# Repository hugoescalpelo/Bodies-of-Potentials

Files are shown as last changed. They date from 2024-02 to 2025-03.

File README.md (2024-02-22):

# Bodies of Potentials
This repository contains details of the maintenance of Bodies of Potentials, an artwork of [Luis Enrique Zela-Koort](https://luisenriquezk.com/), part of [All the Posible Pulses](https://luisenriquezk.com/all_the_possible_pulses/) series.

You can see it working on instagram https://www.instagram.com/p/C0fhJ_dCAHn/

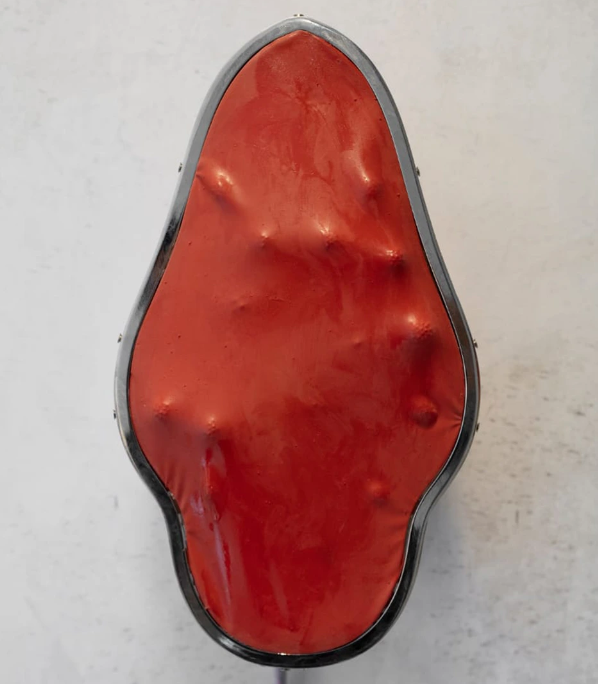
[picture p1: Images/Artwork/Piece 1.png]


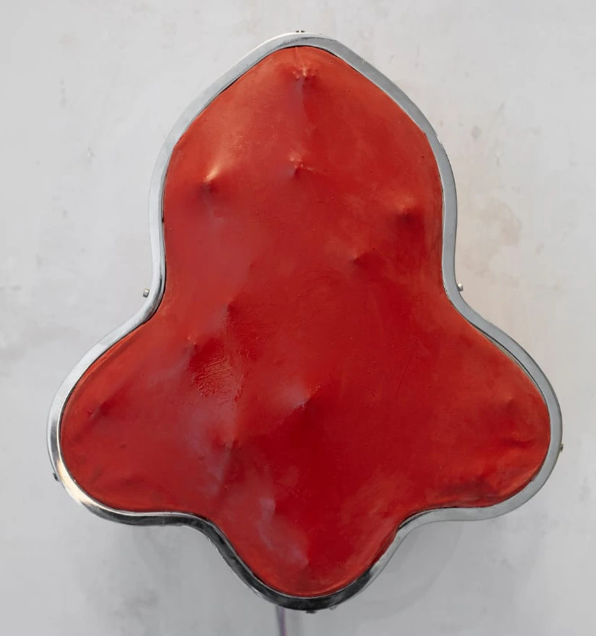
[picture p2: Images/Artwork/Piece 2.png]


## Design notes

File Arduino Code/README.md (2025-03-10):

## Arduino Code

This Arduino code has a history. Check "Hugo Code" Folder, legacy is original code, just for reference.

- I received de original Code
- I map the circuit based on this code
- I test this code alive
- I found the mechanical problems of this code
- Too much friction
- Re print some of the 3d Printed pieces and find new friction points
- Reprinted unsuccesfully
- Reprinted unsuccesfully
- Reprinted unsuccesfully
- Reprinted unsuccesfully
- Reprinted unsuccesfully
- Spring needed
- Reprinted unsuccesfully
- Reprinted unsuccesfully
- Reprinted unsuccesfully
- Reprinted unsuccesfully
- Reprinted succesfully
- Installation problems
- Reprinted unsuccesfully
- Reprinted unsuccesfully
- Reprinted unsuccesfully
- Reprinted unsuccesfully
- Lubricaion needed, silicon WD40 won't make it
- Reprinted unsuccesfully
- Reprinted unsuccesfully
- Reprinted unsuccesfully
- 360 degree motor founded
- All of the motors are 360 degree :()
- Reprinted unsuccesfully
- Reprinted unsuccesfully
- Reprinted unsuccesfully
- Reprinted unsuccesfully
- Reprinted unsuccesfully
- Reprinted unsuccesfully
- Reprinted succesfully. Original Pieces need a 2mm bore up.
- Reprinted unsuccesfully
- Reprinted unsuccesfully
- Reprinted unsuccesfully
- Reprinted unsuccesfully
- Reprinted unsuccesfully
- Why Im like this? I will doom humanity
- Reprinted unsuccesfully
- Reprinted unsuccesfully
- Reprinted unsuccesfully
- Reprinted unsuccesfully
- Reprinted unsuccesfully
- Reprinted unsuccesfully
- Reprinted unsuccesfully
- Reprinted unsuccesfully
- Reprinted unsuccesfully
- Reprinted unsuccesfully
- Just watched the repo
- Just watched the repo
- Just watched the repo
- Just watched the repo
- Just watched the repo
- Just watched the repo
- Just watched the repo
- Oh my god, why this printer does not work
- I Fixed it. Now all prints are beautifull
- Ok, now I can test rigidity and center of servos
- Damn, I need to rewire everything
- Wow, colors! 
- Will this epoxy ever cuajar?
- Earthquake!
- I' so sorry Luis
- Luis, if you ever read this and work with me again, let me let you know I´m not usually like this
- Well, the first test in situ is available

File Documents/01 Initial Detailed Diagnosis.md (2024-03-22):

# Initial Detailed Diagnosis

An extensive revision was made, confirming the main poinst of diagnosis and adding some new recommendations.

A video resume is available here https://youtu.be/R9Tb3EtviOM

## Piece A

### Reported problems

- Damage to the latex membrane after a long period of worktime.
- Water based constant lubrication is needed.
- Some motors stop working due to friction.

### Original diagnosis

- Re design of servo motor holder is needed.
- Re print of spheres with PET-G is needed.
- Substitution of Servo Motors is needed. Metalic gear will be used.
- Aluminum sheet coating to the depth wheel is recommended.
- Silicon based lubricant will be applied.

### New Discoveries

An important difference in damage to the latex membrane was noticed between Piece A and Piece B. Piece A shows damage very noticeable, piece B shows almost no damage. It might be caused due to tension or difference in tickness, but the main cause could be related to the rotary wheel using the membrane tension to reposition the spheres. A spring will be added to every wheel axis to retract without depending of the membrane tension.

The source has no specifications. Sticker with info was removed. Due to its size, power coud be insufficient, causing the motors to stop working. Measurements are in order. If insufficient, source will be replaced.

## Piece B

### Repoted problems
- Damage to the latex membrane after a long period of worktime.
- Water based constant lubrication is needed.
- Some motors stop working due to friction.

### Original diagnosis

- Re design of servo motor holder is needed.
- Re print of spheres with PET-G is needed.
- Substitution of Servo Motors is needed. Metalic gear will be used.
- Aluminum sheet coating to the depth wheel is recommended.
- Silicon based lubricant will be applied.

### New Discoveries

Circuit maintenance is needed. Some conectors are unplugged.

Driver for DC motors might be insufficient, substitusion is needed.

The source has no specifications. Sticker with info was removed. Due to its size, power might be insufficient. Testing and measurements are needed to determine if current is enough. If insufficient, source will be replaced.

Rotary DC mThe source has no specifications. Sticker with info was removed. Due to its size, power coud be insufficient, causing the motors to stop working. Measurements are in order. If insufficient, source will be replaced.

DC motor holder for rotary functions have a very noticeable missalignment, re design of holding mechanism will be performed.

## General Extras

- An extensive test is scheduled after maintenance.
- A prescence sensor will be integrated.

## Requirements

- Step files were proided.
- Electronic schematics are needed.
- Source code is needed.

## Next Steps

- This inform will be delivered to get Artist's conscent to operate the Piece A with membrane damage.
- Water based lubricant will be applied.
- Both pieces will be activated in order to determine further problems.

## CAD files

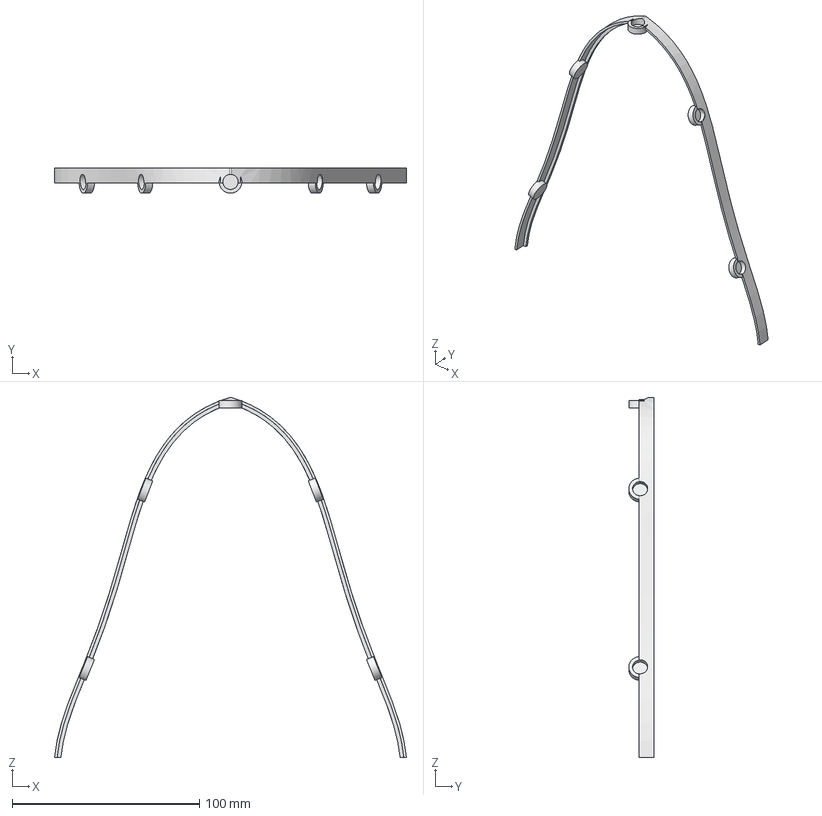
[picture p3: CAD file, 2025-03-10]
STEP/Calamar full V2 Arco A v3.step
188.0 x 13.6 x 192.3 mm

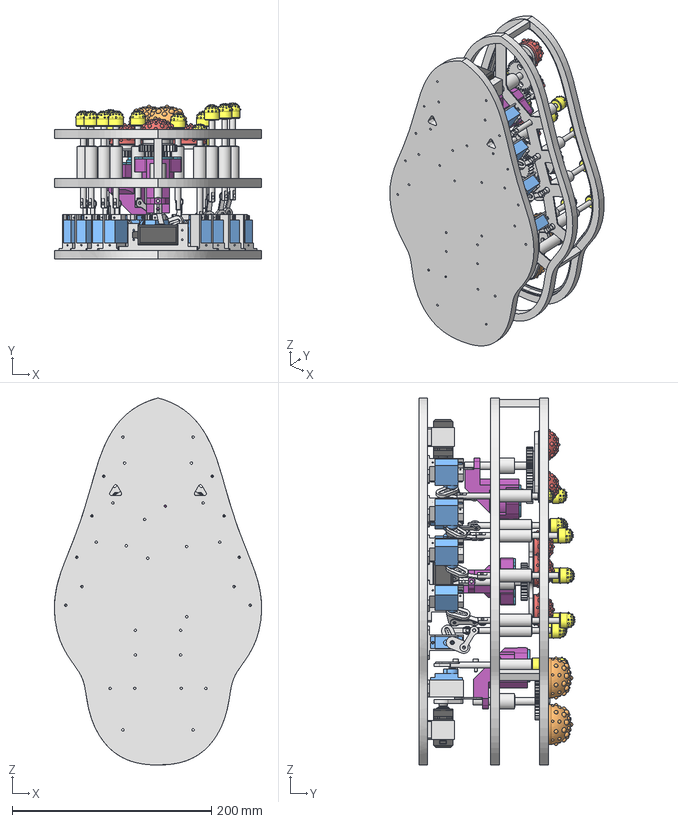
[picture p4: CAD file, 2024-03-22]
STEP/Original Files/Calamar full V2 feb28.stp
208.0 x 157.0 x 368.3 mm
Plataforma inferior v2
Acople brazo servo x 14
brazo servo 1 x 14
Micro Servo SG90 x 14
Soporte Servo sg90 x 14
brazo 20mm x 17
Perfil superior
brazo servo 4 x 3
Acople brazo servo s3003 x 3
Servo S3003 x 3
Soporte Servo s3003 x 3
Perfil ejes v2
Motor DC 10rpm x 3
Eje aluminio 9mm x 3
Eje aluminio b15 x 14
Gear1A x 3
Gear1B x 3
Bocina 6mm x 14
Bocina 9mm
Soporte b40 doble
Soporte b30 doble
Soporte b30 penta
Bola 15mm x 14
Bola 30mm x 7
Bola 40mm x 2
Soporte motor DC v3 x 3
UNI 5931 - M 3 x 10 x 6

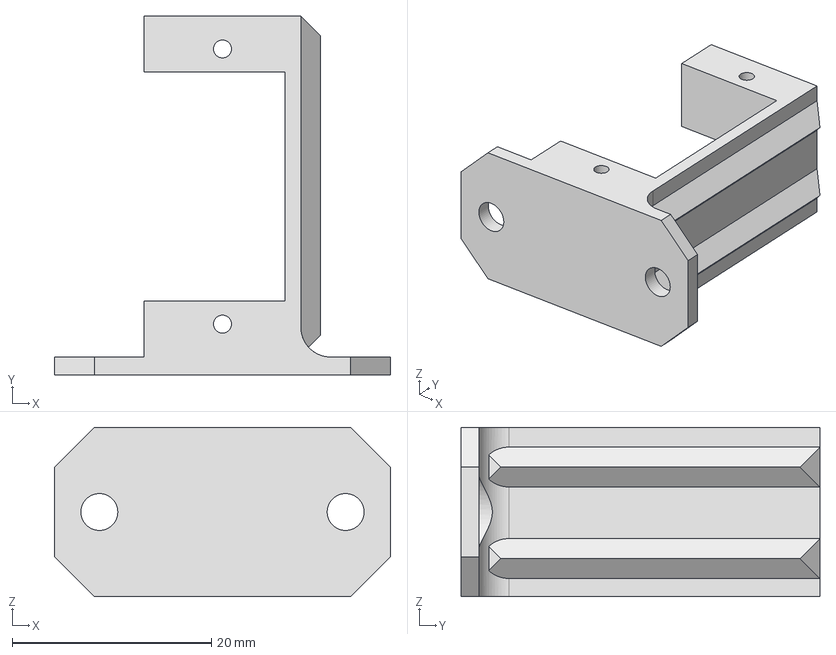
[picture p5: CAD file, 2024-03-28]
STEP/Updated Parts/Calamar full V2 feb28_Soporte Servo sg90 v2.step
33.7 x 36.0 x 17.0 mm

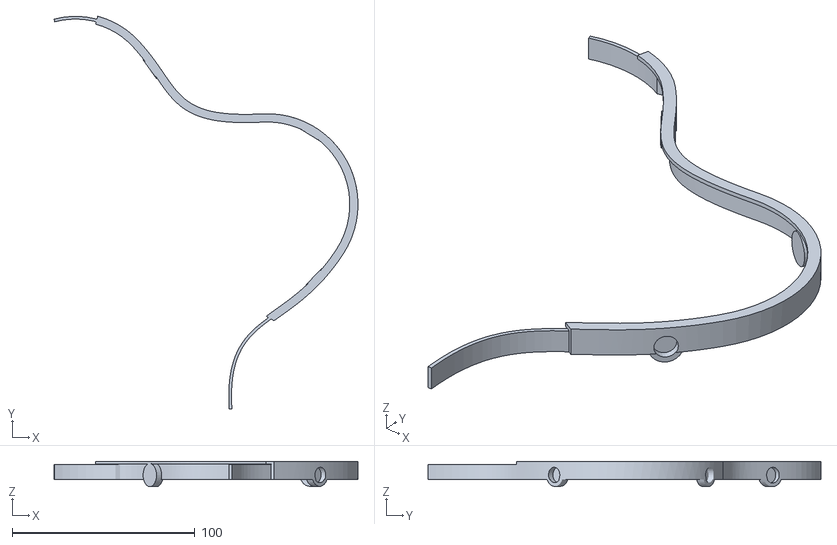
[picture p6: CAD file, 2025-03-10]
STL/Huella full v2 Arco C v5.stl
166.3 x 214.9 x 13.9

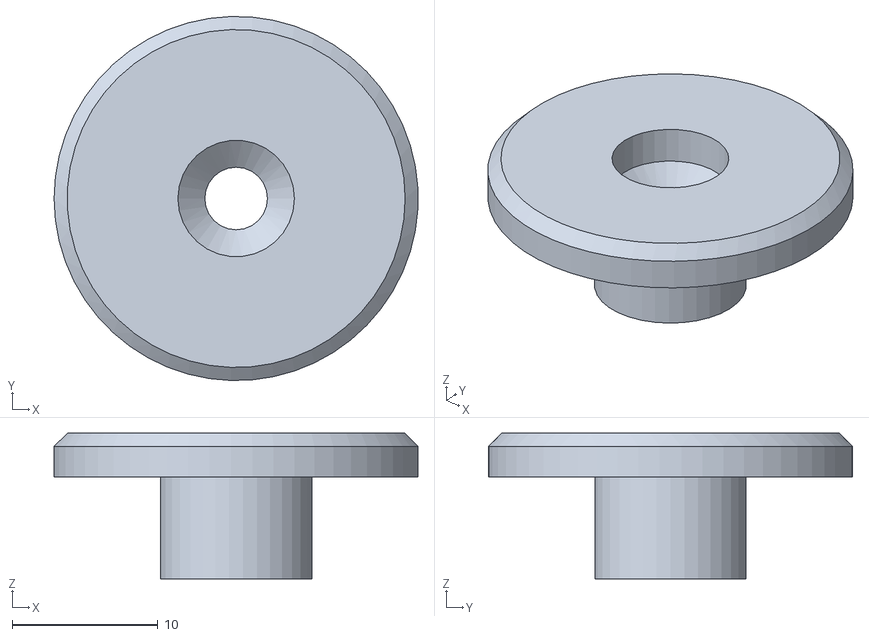
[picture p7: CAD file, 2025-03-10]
STL/Huella full v2 feb28_Gear a1 v1.stl
25.0 x 25.0 x 10.0

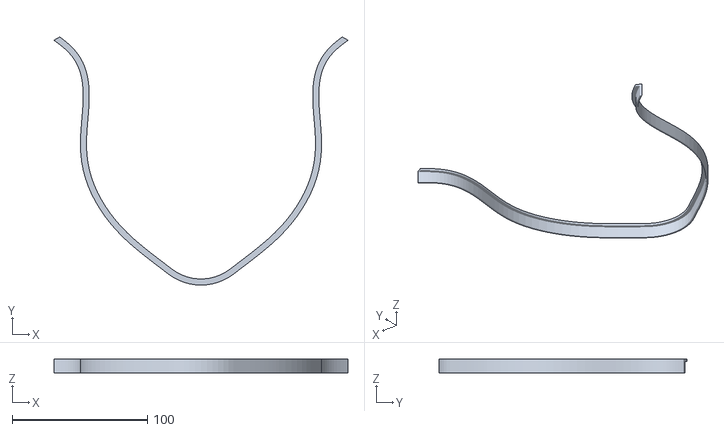
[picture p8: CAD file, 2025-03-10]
STL/Huella full v2 ArcoA v1.stl
217.3 x 183.4 x 10.0

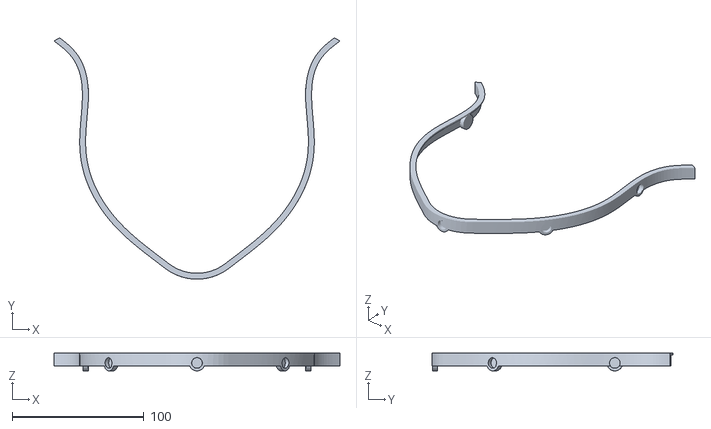
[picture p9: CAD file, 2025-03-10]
STL/Huella full v2 ArcoA v3.stl
217.3 x 183.4 x 13.5

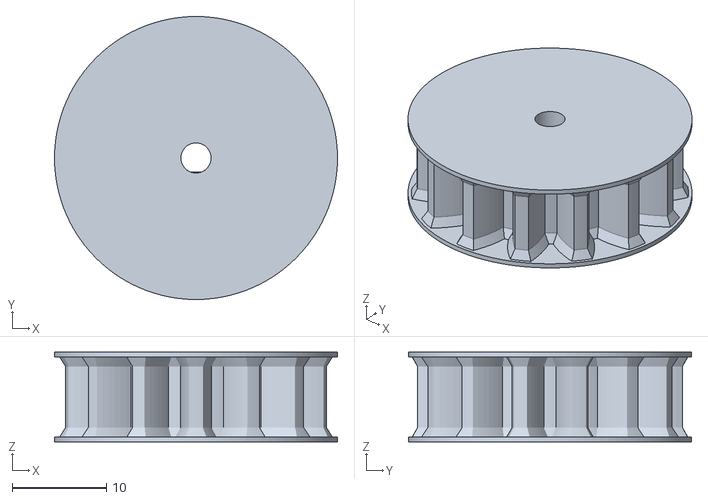
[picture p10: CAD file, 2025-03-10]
STL/Huella full v2 feb28_Gear c2 v2.stl
30.0 x 30.0 x 9.50

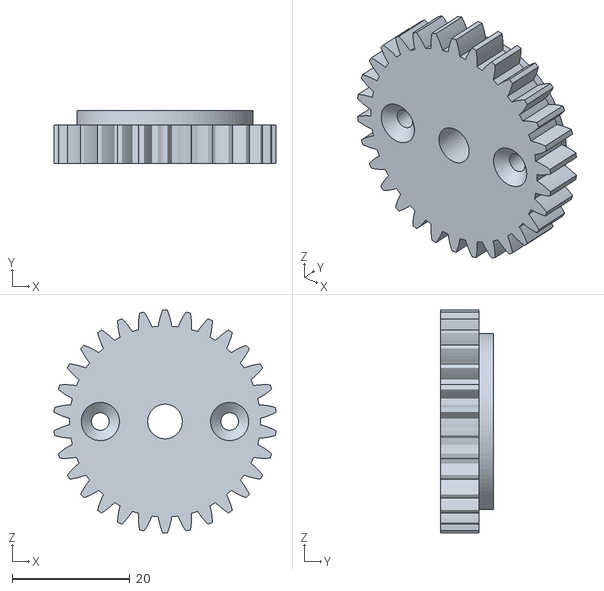
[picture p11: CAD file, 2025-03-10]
STL/Calamar full V2 feb28_Gear1A v3.stl
37.8 x 9.00 x 37.9

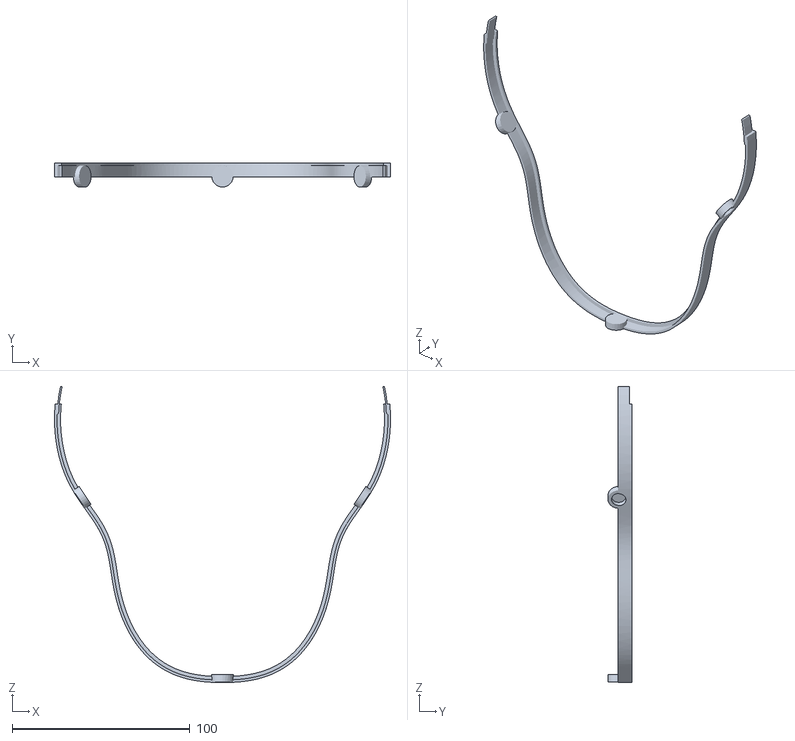
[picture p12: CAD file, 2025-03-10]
STL/Calamar full V2 Arco B v2.stl
188.8 x 13.6 x 166.4

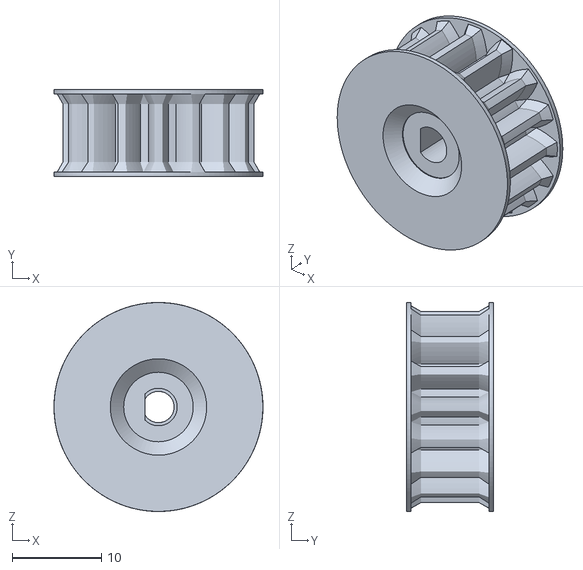
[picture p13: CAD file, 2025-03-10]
STL/Calamar full V2 feb28_Gear1B v2.stl
23.4 x 9.71 x 23.4

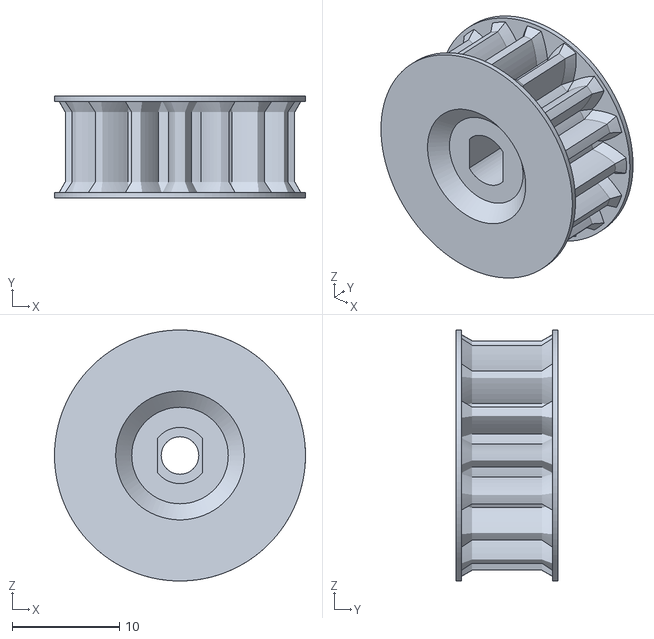
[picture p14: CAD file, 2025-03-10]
STL/Calamar full V2 feb28_Gear1B v2 big.stl
23.4 x 9.50 x 23.4

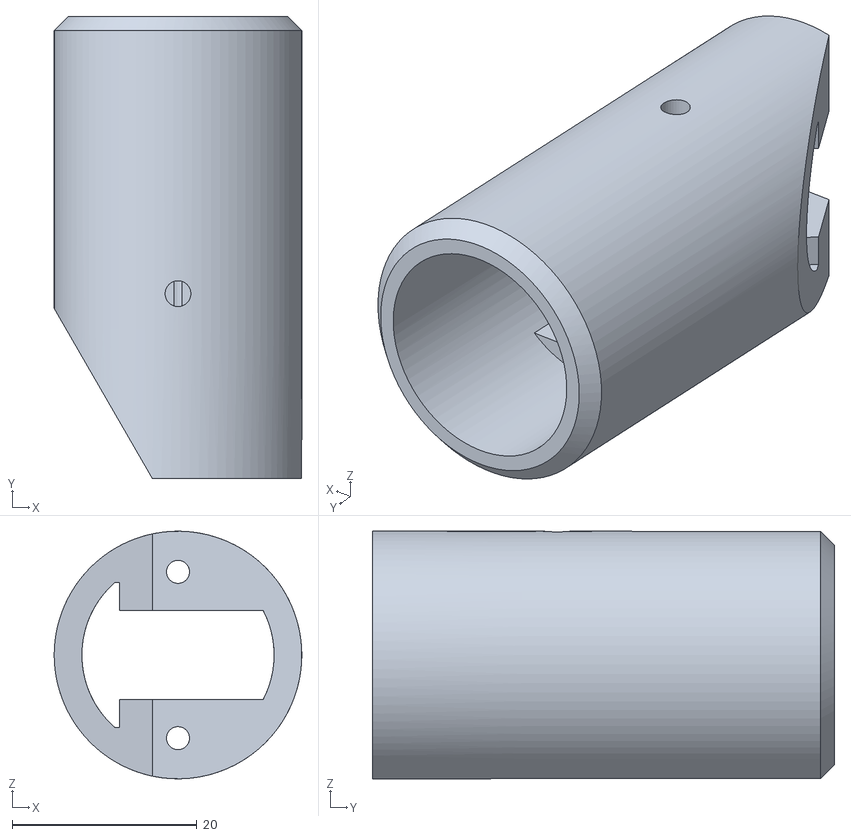
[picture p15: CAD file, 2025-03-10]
STL/Motor Nuevo Huella v3.stl
26.8 x 50.0 x 26.8

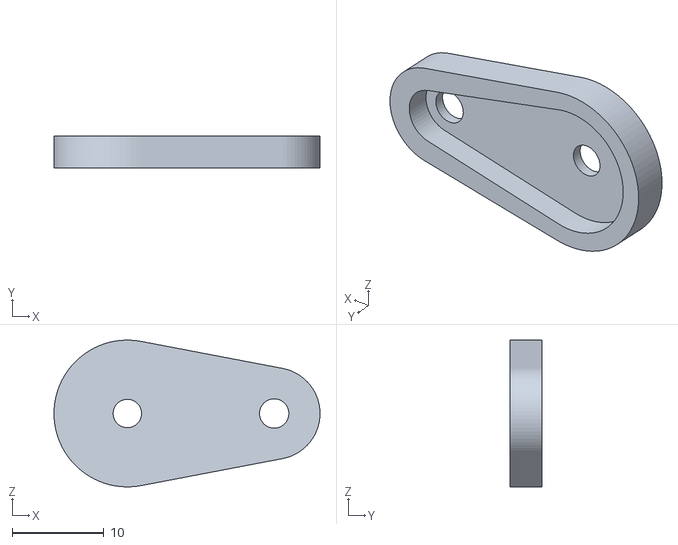
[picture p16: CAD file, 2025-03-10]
STL/Brazo Grande v2.stl
29.0 x 3.50 x 16.0

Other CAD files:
STL/Huella full v2 Arco B v2.stl
STL/Calamar full V2 Arco A v4.stl
STL/Calamar full V2 feb28_Gear1A v2.stl
STL/Calamar full V2 feb28_Soporte Servo sg90 v2.stl
STL/Base Integral v26.stl
STL/Brazo nuevo Calamar.stl
STL/Calamar - Motor Tester v1.stl
STL/Calamar - Motor Tester v2.stl
STL/Calamar - Motor Tester v3.stl
STL/Calamar_New_DC_Motor v4.stl
STL/Calamar_New_DC_Motor v5.stl
STL/Calamar_New_DC_Motor v6.stl
STL/Calamar_New_DC_Motor v7.stl
STL/plate adapter v2.stl

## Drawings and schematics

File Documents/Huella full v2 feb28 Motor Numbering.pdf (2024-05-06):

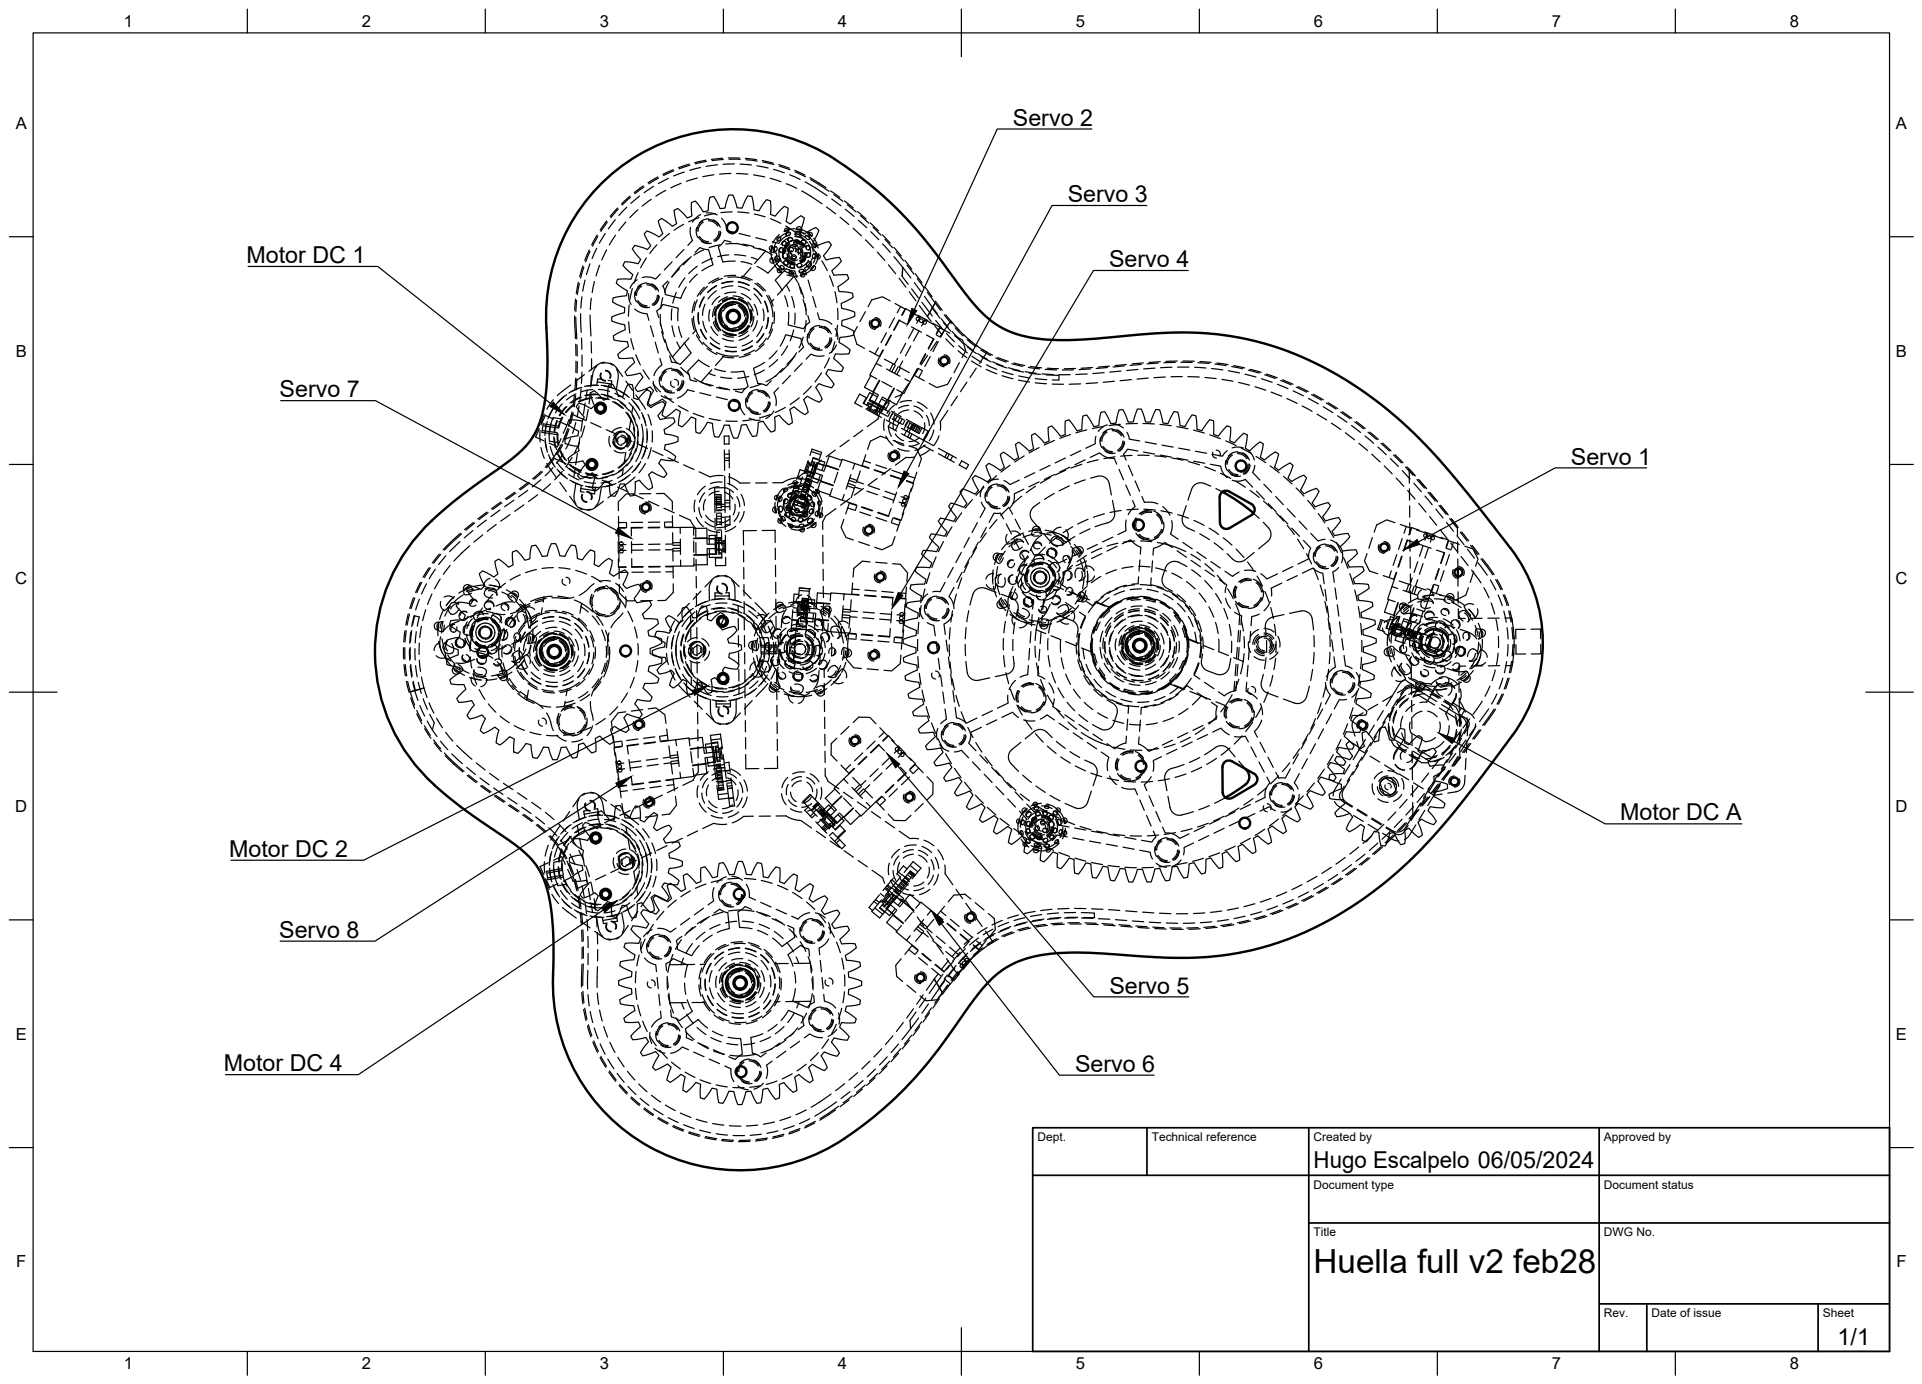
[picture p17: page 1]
Dept.; Technical reference; Created by; Approved by; Document type; Document status; Title; DWG No.; Rev.; Date of issue; Sheet; Huella full v2 feb28; Hugo Escalpelo; Servo 1; Servo 2; Servo 3; Servo 4; Servo 5; Servo 6; Servo 7; Servo 8; Motor DC A; Motor DC 1; Motor DC 2; Motor DC 4

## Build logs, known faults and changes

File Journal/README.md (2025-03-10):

# Journal

This document is a journal about the maintenance of 2024.

## 2023-12-22
Artwork was picked up at Nasal Gallery.

## 2024-01-15
Diagnostics were made, solutions were stated. A part list of refactions was created.

## 2024-02-22

Repository was created. Readme was structured. Register pictures were added. 

## 2024-02-28

STEP files were provided

## 2024-03-17

Maintenance material arrived

## 2024-03-21

Detailed initial diagnosis performed.

Video diagnosis: https://youtu.be/R9Tb3EtviOM

## 2024-03-25

Spare membranes were picked up at the Nasal Gallery

## 2024-03-27

Code was solicited

## 2024-03-28

Motor supports were redesigned, a mechanical test was performed succesfully.
https://youtu.be/EXxLqPLDNS4v

## 2024-04-02

Activation test completed. Both pieces were lubricated and activated to test its mechanical behaviour. It was confirmed the need of springs to retract the Z axis parts. Also, missalignments were found. These miss alignments can be rectified including the springs. A redesign of some gears could help in the alignment of the turning parts. Driver sustitution is confirmed, DC motor sustitusion is on the table. Re print of spheres is needed. DC source measurements are scheduled, substitution is on the table.

## 2024-04-05

Springs were ordered online.
A set of motor holders were 3D printed.

## 2024-04-08

Springs arrived. Compresion test were made, but the K of the spring is too high, new springs are needed.

## 2024-04-12

A search in industrial store section of downtown was performed, no suitable springs were found.

## 2024-04-16

Code was analyzed.

## 2024-05-02

A set of suitable springs were found ad "Anexo Mercado Hidalgo", tests are pending.

## 2024-05-06

A breakdown manual for Huella Full was created. 

## Pending

## 2024-09-03

Installed the soft springs for non membrane dependant retraction

## 2024-09-05

Just changed the circuit to an ESP32

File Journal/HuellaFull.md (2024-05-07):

## Huella Full

Este documento contiene detalles del mantenimiento de Huella Full

## Mecánica de des ensamble

1. Para empezar el des ensamblaje, es no necesario quitar los circuitos primero, pero es buena oportunidad para formalizar las conexiones.

    - La alimentación se conecta de forma directa a la placa del micro controlador, se agrega una terminal de tornillos.
    - Los calbes de datos y alimentación de los drivers y el multiplexor PWM para el control de motores están soldados, por lo que se deben extraer juntas las placas del micro controlador, PWM y drivers de motores DC
    - Los conectores a PWM y drivers están conectados por jumpers y terminales de tornillos, por lo que para desconectar esta sección, se requiere hacer un listado de conexiones.
    - Se recomienda acompañar el listado de conexiones con el desarrollo de un diagrama esquemático de las conexiones
    - Una vez identificadas, listadas y desconectadas todas las terminales de motores, se deben desatornillar las carcasas de los circuitos. Se desarrollarán carcasas nuevas para los circuitos.
2. Para poder acceder a los tornillos de sujección de las bases de motores, es necesario retirar la estructura metálica. Para ello se requiere seguir los siguientes pasos.

    - Retirar la membrana. Se aprovechará para limpiar todos los componentes de residuos de lubricante.
    - Desatornillar todas las esferas acopladas a ejes
    - Desatornillar la estructura metálica

3. En este punto es posible desatornillar cualquier pieza de la base de acrilico y sustitulirla.
    - Algunos tornillos requieren que se extraigan primero otro motor para que las llaves quepan o haya espacio para girarla.
    - Se recomienda sacar todos los servomotores siempre en una posición con el brazo de forma paralela a la base de acrilico

## Tasks

- [ ] Agregar terminal de tornillo para la alimentación a la placa del micro controlador
- [ ] Listado de conexiones
- [ ] Circuito esquemático
- [ ] Diseñar nueva carcasa para los circuitos, estas deberán asegurar las placas con tornillos

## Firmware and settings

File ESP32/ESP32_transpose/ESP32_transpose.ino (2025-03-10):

#include <Wire.h>
#include <Adafruit_PWMServoDriver.h>
Adafruit_PWMServoDriver pca9685 = Adafruit_PWMServoDriver(0x40); // Dirección I2C 0x40

// Configuración del rango de PWM calibrado para los servos
const int SERVO_MIN = 350; // Valor mínimo de PWM para el ángulo inicial calibrado
const int SERVO_MAX = 505; // Valor máximo de PWM para el ángulo final calibrado
const int SERVO_CENTRO = 460; // Valor de PWM para el ángulo central calibrado

// Pines para los motores DC controlados por el puente H
const int motor1A1 = 27;
const int motor1A2 = 26;
const int motor1B1 = 13;
const int motor1B2 = 12;
const int motor2A1 = 17;
const int motor2A2 = 16;
const int motor2B1 = 19; // PWM
const int motor2B2 = 18;

int velocidadMotorPWM = 250; // Velocidad PWM para el motor 2

// Variables para control no bloqueante
unsigned long tiempoAnteriorServos = 0;
unsigned long tiempoAnteriorMotores = 0;
const unsigned long intervaloServo = 10; // Tiempo entre actualizaciones de los servos (ms)
const unsigned long intervaloMotor = 5; // Tiempo entre actualizaciones de los motores (ms)

// Variables para controlar los servos y sus grupos
byte gruposervo[16] = {55, 55, 55, 3, 4, 1, 2, 55, 55, 0, 5, 3, 2, 55, 55, 55}; // Grupo de cada servo
int posiciones[16];
int velocidades[16][5] = {0}; // Velocidades y estados de los servos

float Tiempos[16][3] = {{2.5, 2, 2}, {4, 1.5, 2}, {1.5, 2.5, 3}, {3, 2.5, 1.5}, {2, 0.5, 1}, {1, 0.5, 2}};
byte Bsubidalista[16], Bbajadalista[16];
int ContadorPausa[16];
float Texe = 5.08;
float Textra = 46.7;

void setup() {
  Serial.begin(115200);
  Serial.println("Iniciando ESP32 para control de motores y servos...");

  // Inicializa la comunicación I2C
  Wire.begin(21, 22); // SDA en GPIO 21, SCL en GPIO 22

  // Inicializa el módulo PCA9685
  pca9685.begin();
  pca9685.setPWMFreq(50);

  // Configura los pines de los motores como salidas
  pinMode(motor1A1, OUTPUT);
  pinMode(motor1A2, OUTPUT);
  pinMode(motor1B1, OUTPUT);
  pinMode(motor1B2, OUTPUT);
  pinMode(motor2A1, OUTPUT);
  pinMode(motor2A2, OUTPUT);
  pinMode(motor2B1, OUTPUT);
  pinMode(motor2B2, OUTPUT);
  desactivarMotores();

  // Inicializa las posiciones de los servos
  for (int i = 0; i < 16; i++) {
    posiciones[i] = SERVO_CENTRO;
  }

  // Configuración de tiempos de subida y bajada
  float Periodo = Texe + Textra;
  for (int i = 0; i <= 5; i++) {
    Bsubidalista[i] = round(Periodo * 0.218 / Tiempos[i][0]);
    ContadorPausa[i] = round(Tiempos[i][1] * 1000 / Periodo) - 1;
    Bbajadalista[i] = round(Periodo * 0.218 / Tiempos[i][2]);
  }

  // Asignación de velocidades
  for (int i = 0; i < 16; i++) {
    velocidades[i][0] = (gruposervo[i] == 55) ? 0 : Bsubidalista[gruposervo[i]];
    velocidades[i][1] = (gruposervo[i] == 55) ? 0 : ContadorPausa[gruposervo[i]];
    velocidades[i][2] = (gruposervo[i] == 55) ? 0 : -Bbajadalista[gruposervo[i]];
  }

  // Mueve los servos a la posición inicial
  for (int i = 3; i < 14; i++) {
    moverServo(i, posiciones[i]);
  }

  activarMotores();
}

void loop() {
  unsigned long tiempoActual = millis();

  // Actualización no bloqueante para servos
  if (tiempoActual - tiempoAnteriorServos >= intervaloServo) {
    actualizarServos();
    tiempoAnteriorServos = tiempoActual;
  }

  // Actualización no bloqueante para motores
  if (tiempoActual - tiempoAnteriorMotores >= intervaloMotor) {
    actualizarMotores();
    tiempoAnteriorMotores = tiempoActual;
  }
}

// Función para actualizar los estados de los servos
void actualizarServos() {
  for (int i = 3; i < 13; i++) {
    switch (velocidades[i][3]) {
      case 0:
        if (posiciones[i] < SERVO_MAX) {
          moverServo(i, posiciones[i]);
          posiciones[i] += velocidades[i][0];
        } else {
          velocidades[i][3]++;
          posiciones[i] = SERVO_MAX;
        }
        break;
      case 1:
        if (velocidades[i][4] < velocidades[i][1]) {
          velocidades[i][4]++;
        } else {
          velocidades[i][3]++;
          velocidades[i][4] = 0;
        }
        break;
      case 2:
        if (posiciones[i] > SERVO_MIN) {
          moverServo(i, posiciones[i]);
          posiciones[i] += velocidades[i][2];
        } else {
          velocidades[i][3] = 0;
          posiciones[i] = SERVO_MIN;
        }
        break;
    }
  }
}

// Función para activar los motores en un solo sentido
void activarMotores() {
  digitalWrite(motor1A1, HIGH);
  digitalWrite(motor1A2, LOW);
  digitalWrite(motor1B1, HIGH);
  digitalWrite(motor1B2, LOW);
  digitalWrite(motor2A1, HIGH);
  digitalWrite(motor2A2, LOW);
  analogWrite(motor2B1, velocidadMotorPWM); // Controla la velocidad con PWM
  digitalWrite(motor2B2, LOW);
}

// Función para actualizar el estado de los motores DC
void actualizarMotores() {
  // Actualmente, se mantiene la activación continua en un solo sentido
  activarMotores();
}

// Función para mover un servo a una posición específica
void moverServo(int numServo, int pwmValue) {
  if (gruposervo[numServo] == 55) return;
  pca9685.setPWM(numServo, 0, pwmValue);
}

// Función para desactivar los motores
void desactivarMotores() {
  digitalWrite(motor1A1, LOW);
  digitalWrite(motor1A2, LOW);
  digitalWrite(motor1B1, LOW);
  digitalWrite(motor1B2, LOW);
  digitalWrite(motor2A1, LOW);
  digitalWrite(motor2A2, LOW);
  analogWrite(motor2B1, 0); // Detiene el PWM
  digitalWrite(motor2B2, LOW);
}

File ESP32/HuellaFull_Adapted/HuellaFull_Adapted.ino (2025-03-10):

#include <Wire.h>
#include <Adafruit_PWMServoDriver.h>
Adafruit_PWMServoDriver pca9685 = Adafruit_PWMServoDriver(0x40); // Dirección I2C 0x40 por defecto

int velocidadMotorPWM = 250;

const byte motor1A1 = 27; // A-1A del driver A
const byte motor1A2 = 26; // A-1B del driver A
const byte motor1B1 = 13; // B1-A del driver A
const byte motor1B2 = 12; // B2-A del driver A

const byte motor2A1 = 17; // A-1A del driver B
const byte motor2A2 = 16; // A-1B del driver B
const byte motor2B1 = 19; // B-1A del driver B (PWM)
const byte motor2B2 = 18; // B-2A del driver B

bool motor1Activado = false;
bool motor2Activado = false;

// Configuración del rango de PWM calibrado para los servos
const int SERVO_MIN = 350; // Valor mínimo de PWM para el ángulo inicial calibrado
const int SERVO_MAX = 505; // Valor máximo de PWM para el ángulo final calibrado
const int SERVO_CENTRO = 460; // Valor de PWM para el ángulo central calibrado

void setup() {
  Serial.begin(115200);
  Serial.println("Iniciando prueba de servomotores con rango calibrado...");

  // Inicializa la comunicación I2C
  Wire.begin(21, 22); // SDA en GPIO 21, SCL en GPIO 22

  // Inicializa el módulo PCA9685
  pca9685.begin();
  pca9685.setPWMFreq(50); // Frecuencia de 50 Hz para control de servos

  // Configuración de los pines como salidas
  pinMode(motor1A1, OUTPUT);
  pinMode(motor1A2, OUTPUT);
  pinMode(motor1B1, OUTPUT);
  pinMode(motor1B2, OUTPUT);
  
  pinMode(motor2A1, OUTPUT);
  pinMode(motor2A2, OUTPUT);
  pinMode(motor2B1, OUTPUT);
  pinMode(motor2B2, OUTPUT);

  // Inicialización de los motores apagados
  apagarMotores();

  // Coloca todos los servos en la posición central
  for (int i = 0; i < 11; i++) {
    moverServo(i, SERVO_CENTRO);
  }
  delay(2000); // Pausa de 5 segundos en la posición central

}

void loop() {
  // Ejemplo de prueba: encender los motores si no están activados
  if (!motor1Activado) {
    activarMotor1();  // Activa el motor 1 en un sentido
    motor1Activado = true;
  }
  
  if (!motor2Activado) {
    activarMotor2();  // Activa el motor 2 con PWM en un sentido
    motor2Activado = true;
  }
  
  
  // Mantener los motores encendidos indefinidamente
  delay(1000);

  // Mover suavemente todos los servos al ángulo mínimo calibrado
  for (int i = 0; i < 11; i++) {
    moverSuavemente(i, SERVO_CENTRO, SERVO_MIN);
  }
  delay(1000); // Quedarse 2 segundos en la posición mínima

  // Mover suavemente todos los servos al ángulo central calibrado
  for (int i = 0; i < 11; i++) {
    moverSuavemente(i, SERVO_MIN, SERVO_CENTRO);
  }
  delay(2000); // Quedarse 5 segundos en el centro

  // Mover suavemente todos los servos al ángulo máximo calibrado
  for (int i = 0; i < 11; i++) {
    moverSuavemente(i, SERVO_CENTRO, SERVO_MAX);
  }
  delay(1000); // Quedarse 2 segundos en la posición máxima

  // Mover suavemente todos los servos al ángulo central calibrado
  for (int i = 0; i < 11; i++) {
    moverSuavemente(i, SERVO_MAX, SERVO_CENTRO);
  }
  delay(2000); // Quedarse 5 segundos en el centro
}

// Función para activar el motor 1 en un solo sentido
void activarMotor1() {
  // Activa en un solo sentido
  digitalWrite(motor1A1, HIGH);
  digitalWrite(motor1A2, LOW);
  digitalWrite(motor1B1, HIGH);
  digitalWrite(motor1B2, LOW);
}

// Función para activar el motor 2 con control PWM en un solo sentido
void activarMotor2() {
  // Activa en un solo sentido con control PWM
  digitalWrite(motor2A1, HIGH);
  digitalWrite(motor2A2, LOW);
  analogWrite(motor2B1, velocidadMotorPWM); // Controla la velocidad con PWM
  digitalWrite(motor2B2, LOW);
}

// Función para apagar todos los motores
void apagarMotores() {
  digitalWrite(motor1A1, LOW);
  digitalWrite(motor1A2, LOW);
  digitalWrite(motor1B1, LOW);
  digitalWrite(motor1B2, LOW);
  
  digitalWrite(motor2A1, LOW);
  digitalWrite(motor2A2, LOW);
  digitalWrite(motor2B1, LOW);
  digitalWrite(motor2B2, LOW);
}

// Función para mover un servo a una posición específica
void moverServo(int numServo, int pwmValue) {
  pca9685.setPWM(numServo, 0, pwmValue);
  Serial.print("Servo ");
  Serial.print(numServo);
  Serial.print(" movido a valor PWM: ");
  Serial.println(pwmValue);
}

// Función para mover suavemente el servo desde un valor PWM a otro
void moverSuavemente(int numServo, int desde, int hasta) {
  int paso = (desde < hasta) ? 1 : -1;
  for (int pwmValue = desde; pwmValue != hasta; pwmValue += paso) {
    moverServo(numServo, pwmValue);
    delay(5); // Ajusta el valor para un movimiento más suave o rápido
  }
}

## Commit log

2024-03-22 Initial Detailed Diagnosis was added
    [Calamar full V2 feb28.stp]
2024-03-28 Motor support added
    [Calamar full V2 feb28.stp, Calamar full V2 feb28_Soporte Servo sg90 v2.step, Calamar full V2 feb28_Soporte Servo sg90 v2.stl]
2024-05-06 Tareas de mantenimiento de HuellaFull agregadas
2024-05-06 Instrucciones de des ensamblaje de Huella Full agregadas
2024-05-06 Create Huella full v2 feb28 Motor Numbering.pdf
2024-05-07 Códigos Arduino revisados
2025-03-10 Modificaciones agregadas
    [Base Integral v26.stl, Brazo Grande v2.stl, Brazo nuevo Calamar.stl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]
